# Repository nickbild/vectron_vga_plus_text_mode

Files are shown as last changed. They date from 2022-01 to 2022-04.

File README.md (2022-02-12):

# Vectron VGA Plus Text Mode

Vectron VGA Plus Text Mode simplifies displaying text with retro computers and microcontrollers by hiding the pixel-level details.  Supply only row and column positions, and an ASCII character code, to write text to a 40x30 character VGA display.

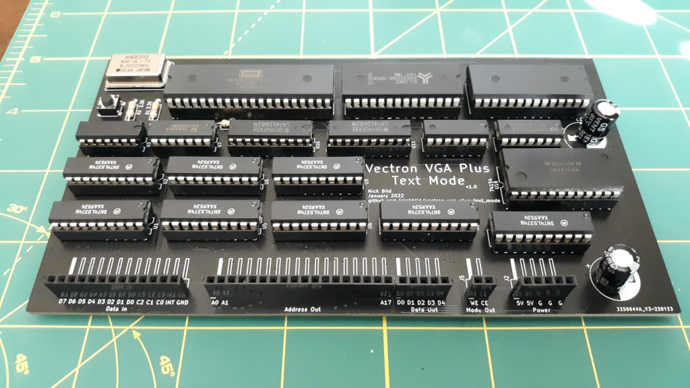
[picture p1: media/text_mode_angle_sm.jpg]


## How It Works

Vectron VGA Plus Text Mode accepts row, column, and character codes into 8-bit flip flop registers from external systems.  Using a 6502 processor and pre-programmed ROM chip ([code here](https://github.com/nickbild/vectron_vga_plus_text_mode/blob/main/os.asm)), these values are translated into a series of pixels to be drawn at x,y coordinates on the screen.  Both the program, and the library of available ASCII characters are stored in the ROM.  Instructions to draw each pixel are stored in 8-bit flip flop output registers where they can interface with and control a [Vectron VGA Plus](https://github.com/nickbild/vectron_vga_plus) VGA adapter.  Text Mode also handles initialization of a blank screen on the VGA adapter on startup.

To write a single 8x8 character to the screen without Text Mode would require writing 64 individual pixels, and performing all of the associated instructions and data transformations.  This would keep a typical 6502 computer pretty busy just writing to the screen, not to mention all of the other things the computer needs to do.  Text Mode allows for the same result with just a few instructions from the interfacing device.

At the heart of the design is a 65C02 processor to handle the somewhat complex calculations that would be difficult to perform with only logic chips, and would require a high part count.  I think using a microprocessor in this board is well within the bounds of being acceptable for a pure retro computing device, considering that the Commodore 1541 disk drive, for example, also had its own 6502 to handle processing.

An Arudino sketch that can be used to write characters using Text Mode [is here](https://github.com/nickbild/vectron_vga_plus_text_mode/tree/main/ardunio_tester).  KiCad design files are [available here](https://github.com/nickbild/vectron_vga_plus_text_mode/tree/main/kicad).  You will also need a [Vectron VGA Plus](https://github.com/nickbild/vectron_vga_plus) VGA adapter, which Text Mode was designed to work with.

## Media

Vectron VGA Plus Text Mode:

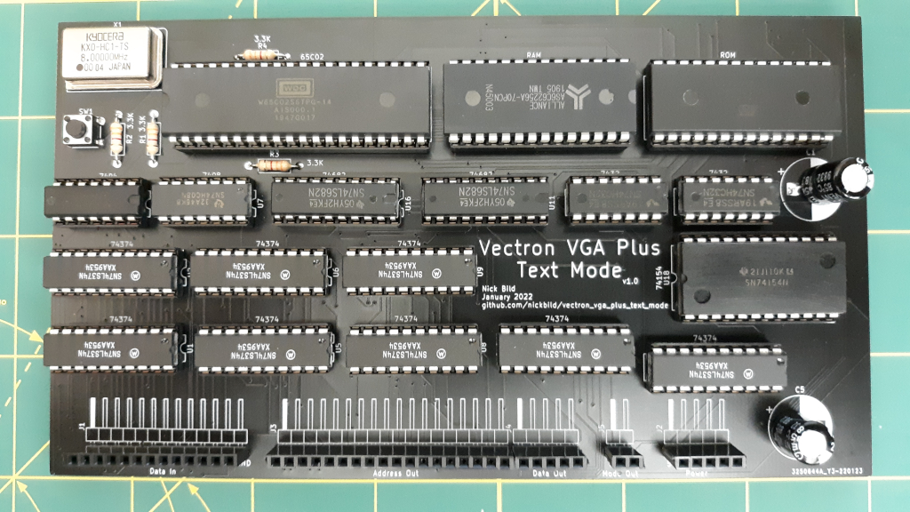
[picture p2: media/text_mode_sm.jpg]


Vectron VGA Plus Text Mode attached to Vectron VGA Plus, with an Arduino Mega 2560 requesting the characters to be written on screen:

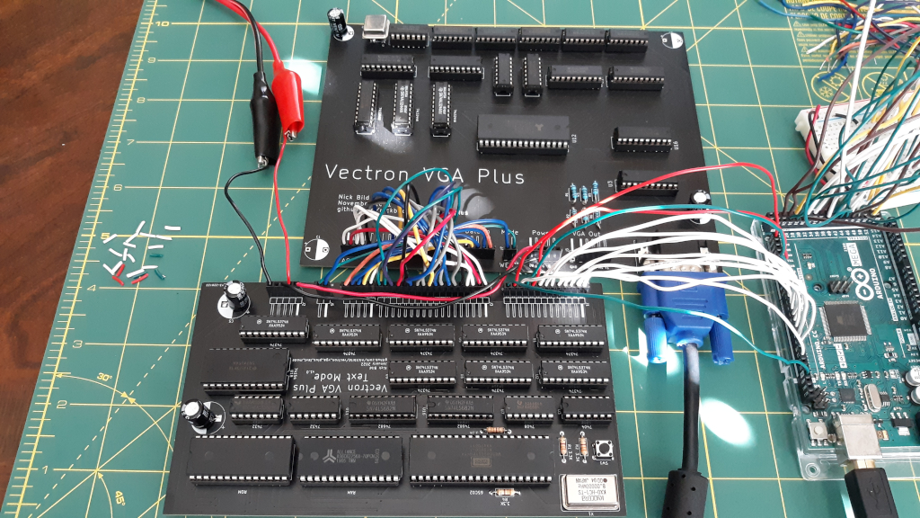
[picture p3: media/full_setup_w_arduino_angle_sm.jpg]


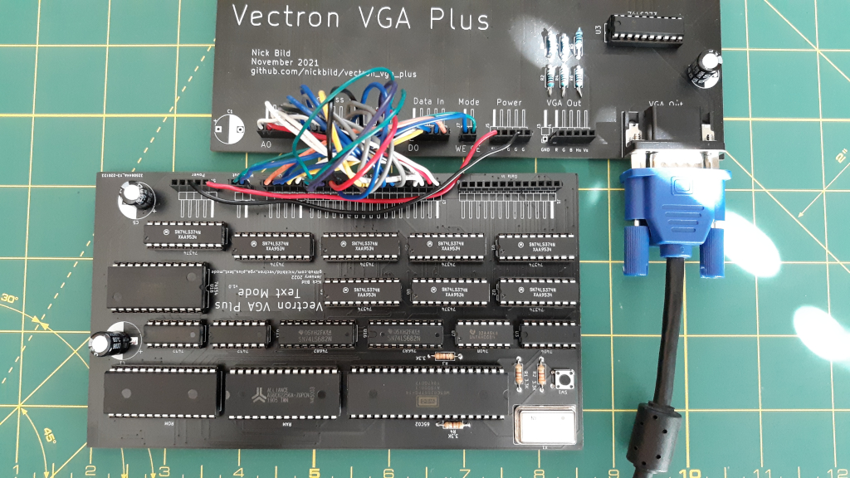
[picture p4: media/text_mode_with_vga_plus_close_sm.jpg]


All characters in a repeating pattern:

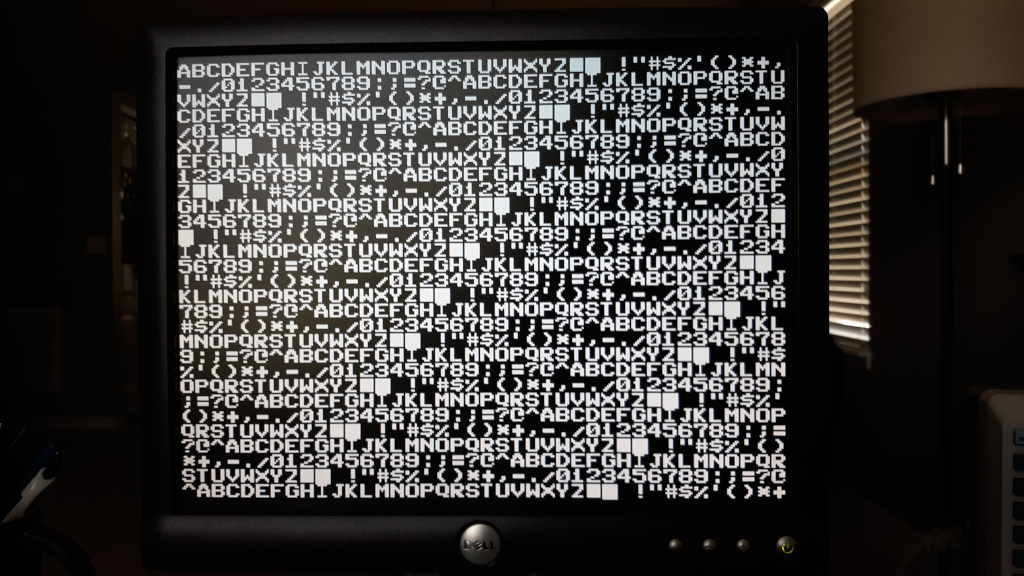
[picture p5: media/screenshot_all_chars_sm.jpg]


Text mode interface:

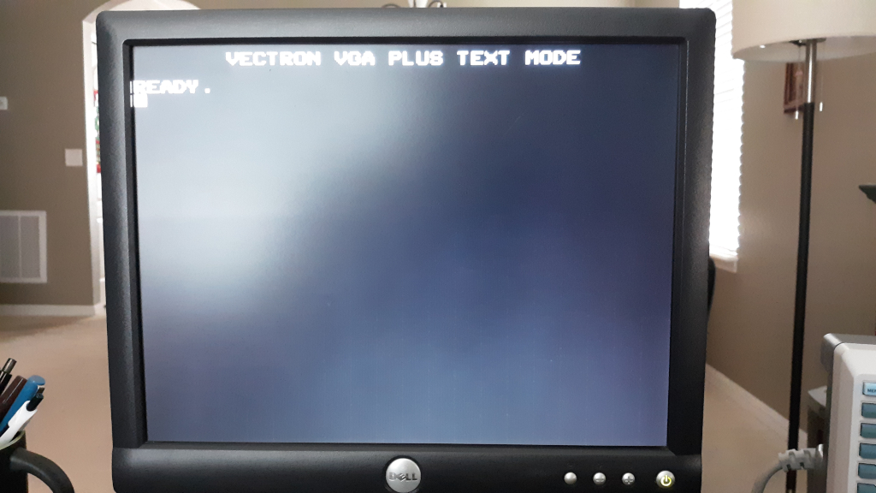
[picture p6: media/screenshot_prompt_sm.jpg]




Breadboard prototype (with a few components removed to place on the PCB):

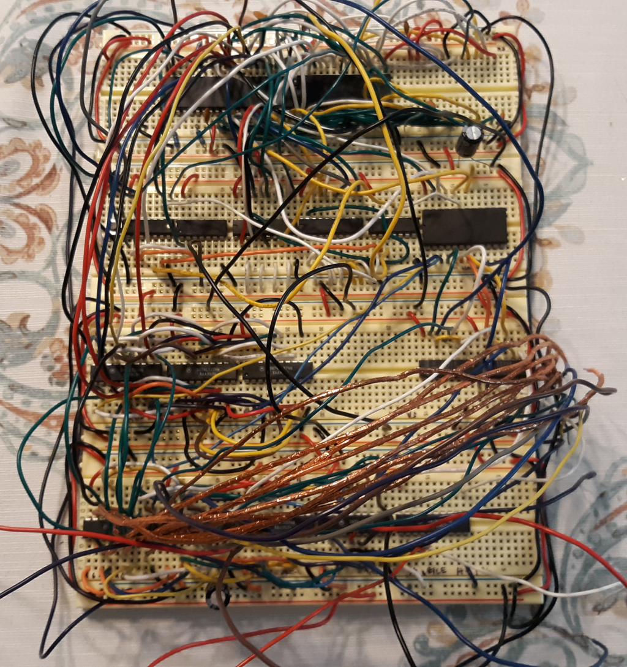
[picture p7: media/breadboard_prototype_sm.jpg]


## Bill of Materials

- 1 x WDC 65C02 processor
- 1 x AS6C62256A-70PCN 32KB RAM
- 1 x AT28C256-15PU 32KB ROM
- 1 x 8 MHz oscillator
- 4 x 3.3k ohm resistors
- 2 x 220 uF capacitors
- 1 x push button
- 2 x 7432
- 1 x 7408
- 1 x 7404
- 2 x 74682
- 1 x 74154
- 8 x 74374
- Female headers
- PCB ([KiCad design files](https://github.com/nickbild/vectron_vga_plus_text_mode/tree/main/kicad))

## About the Author

[Nick A. Bild, MS](https://nickbild79.firebaseapp.com/#!/)

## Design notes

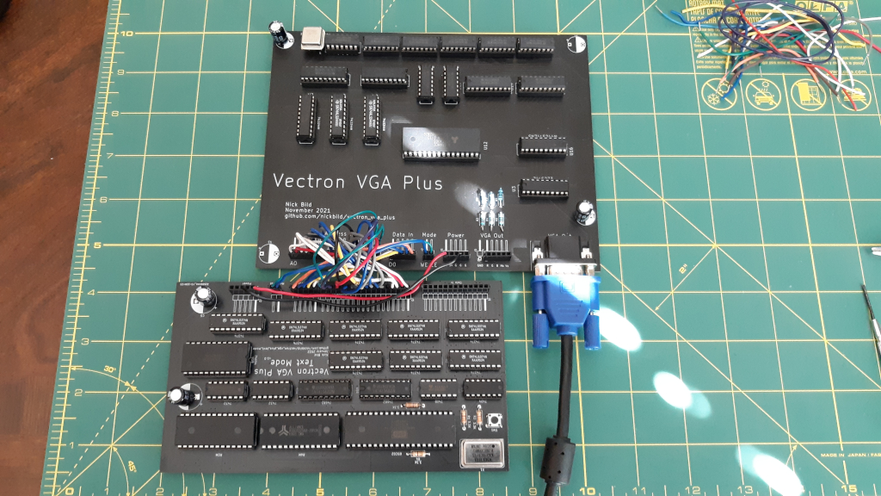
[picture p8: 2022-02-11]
media/text_mode_with_vga_plus_sm.jpg

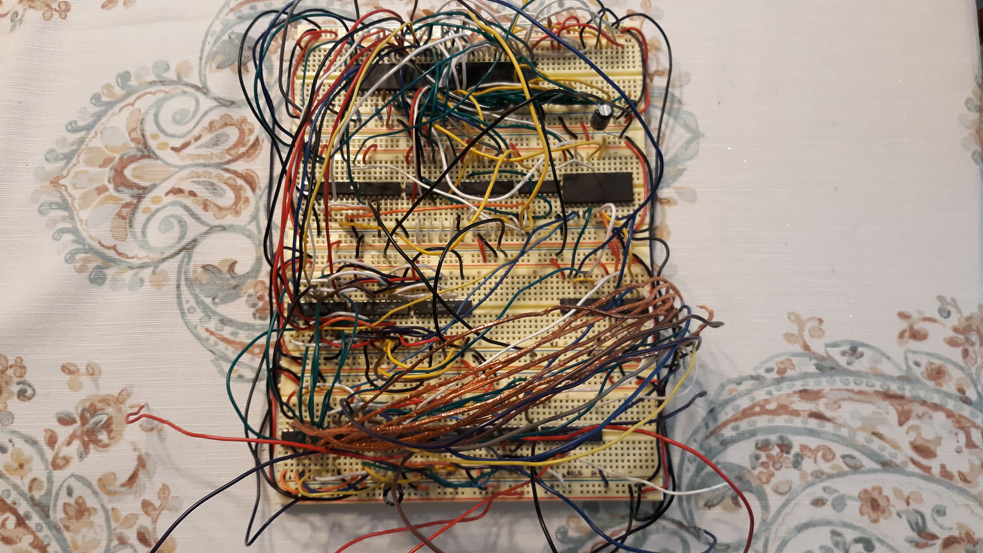
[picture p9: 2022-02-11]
media/breadboard_prototype.jpg

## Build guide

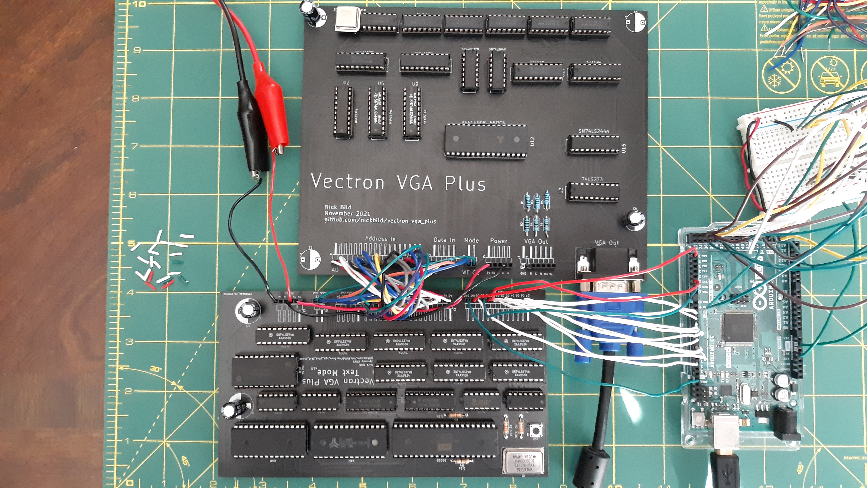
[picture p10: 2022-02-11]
media/full_setup_w_arduino.jpg

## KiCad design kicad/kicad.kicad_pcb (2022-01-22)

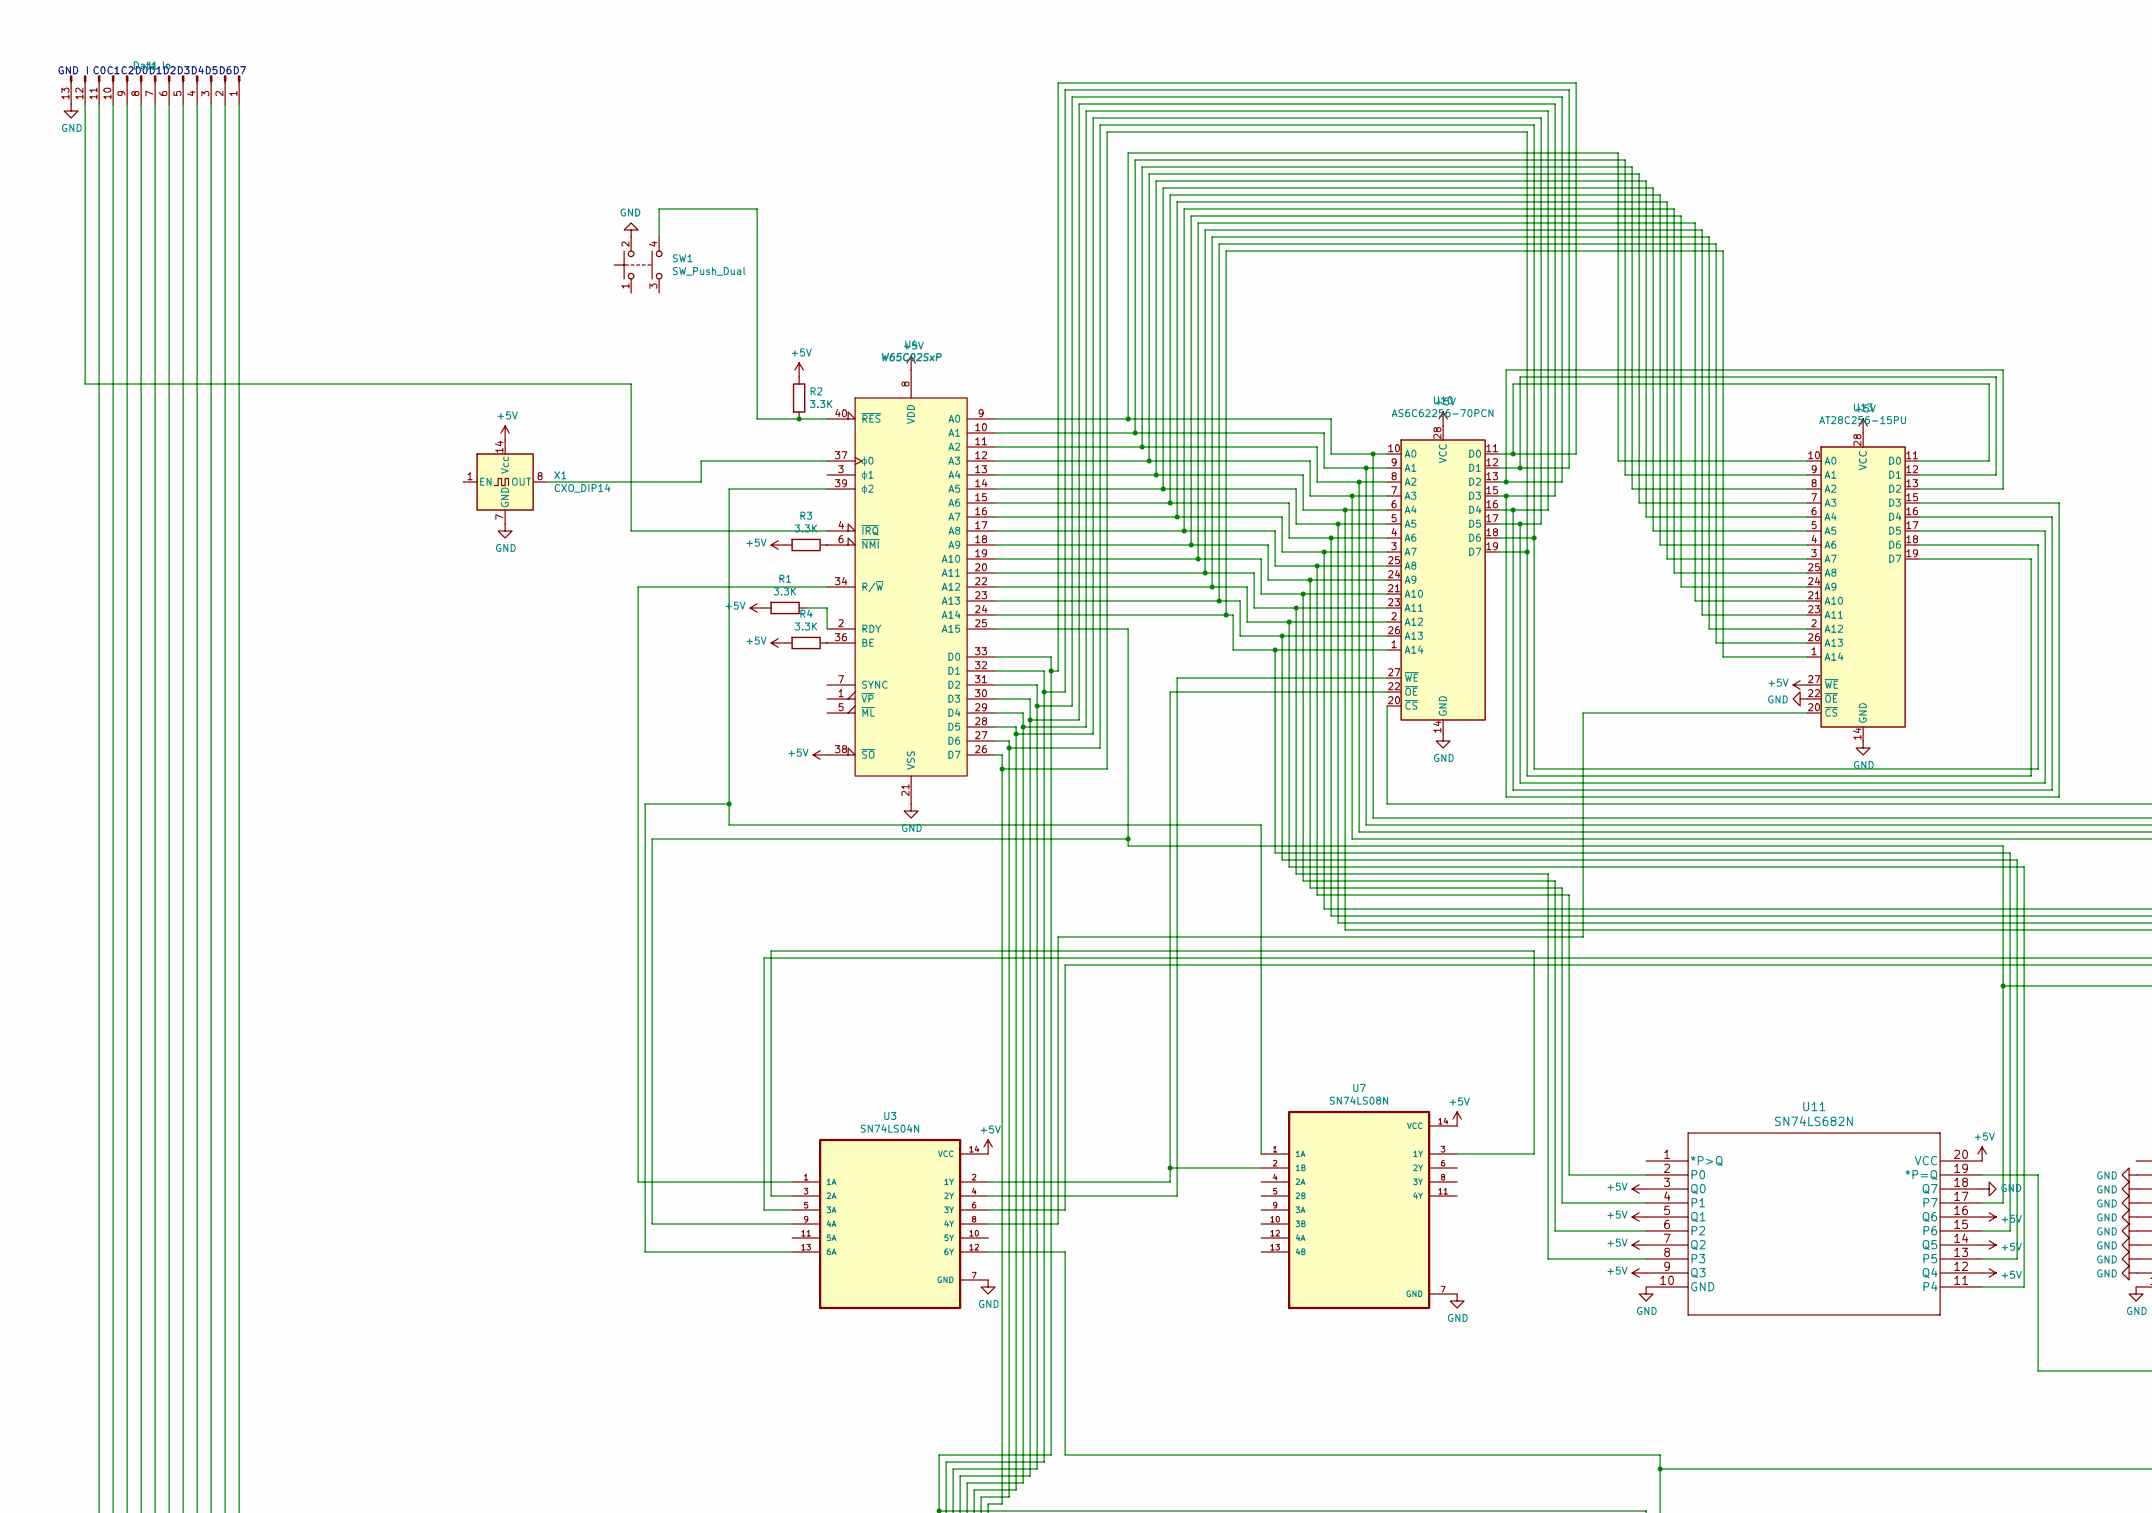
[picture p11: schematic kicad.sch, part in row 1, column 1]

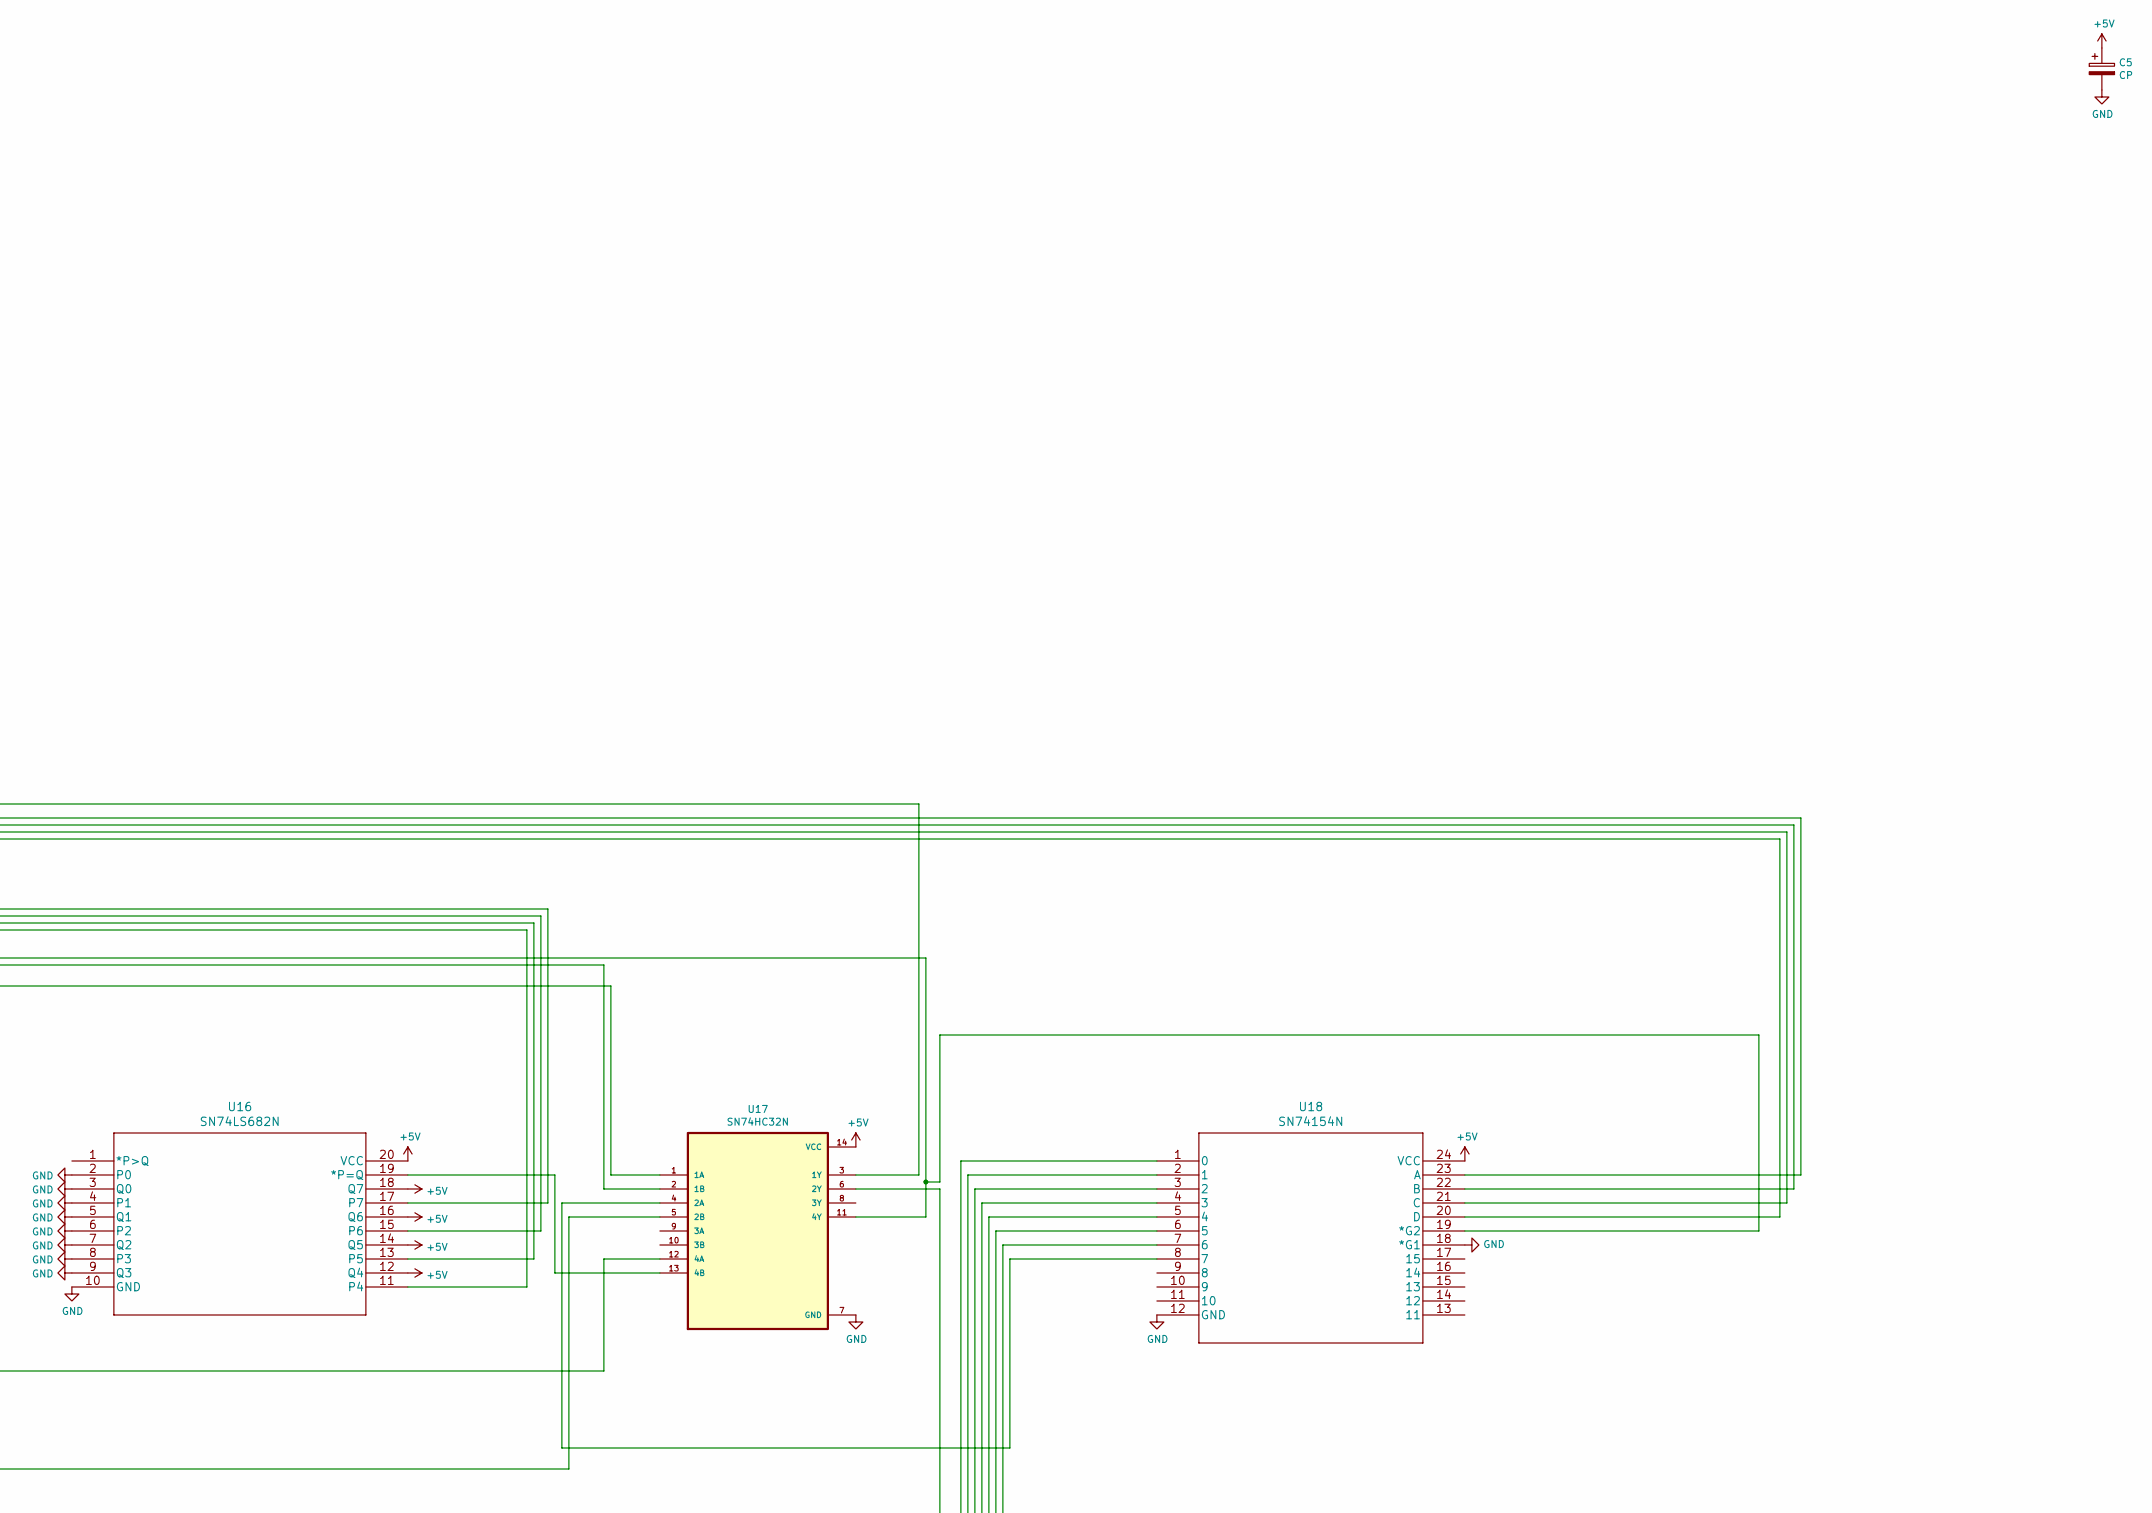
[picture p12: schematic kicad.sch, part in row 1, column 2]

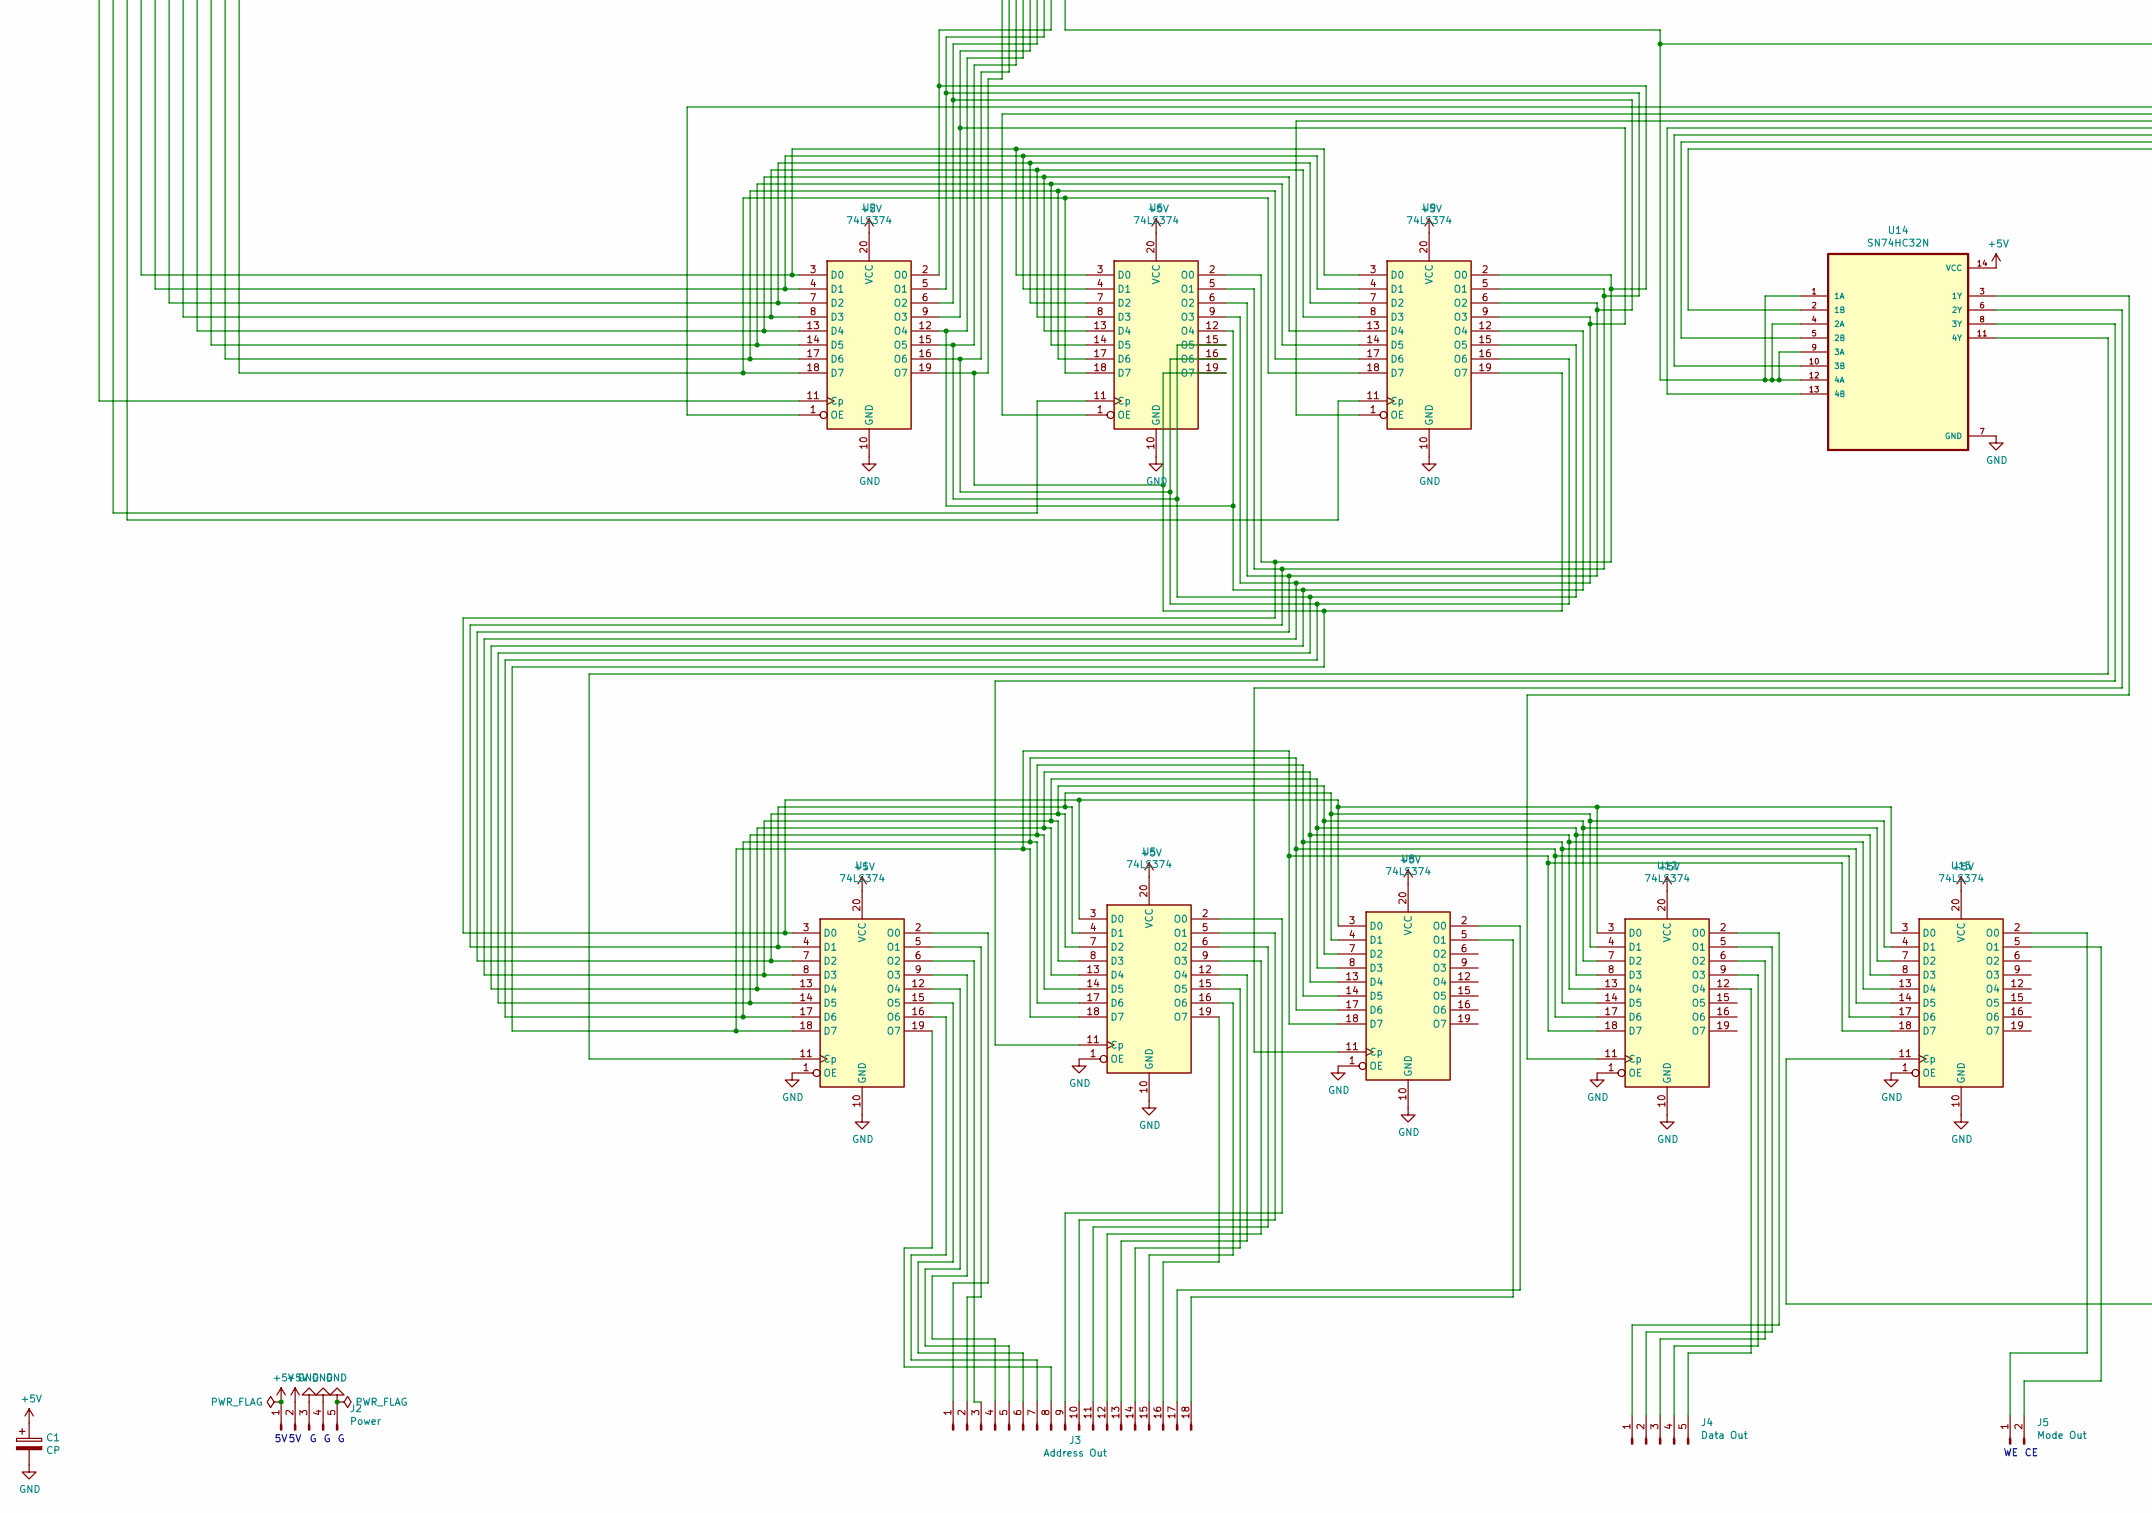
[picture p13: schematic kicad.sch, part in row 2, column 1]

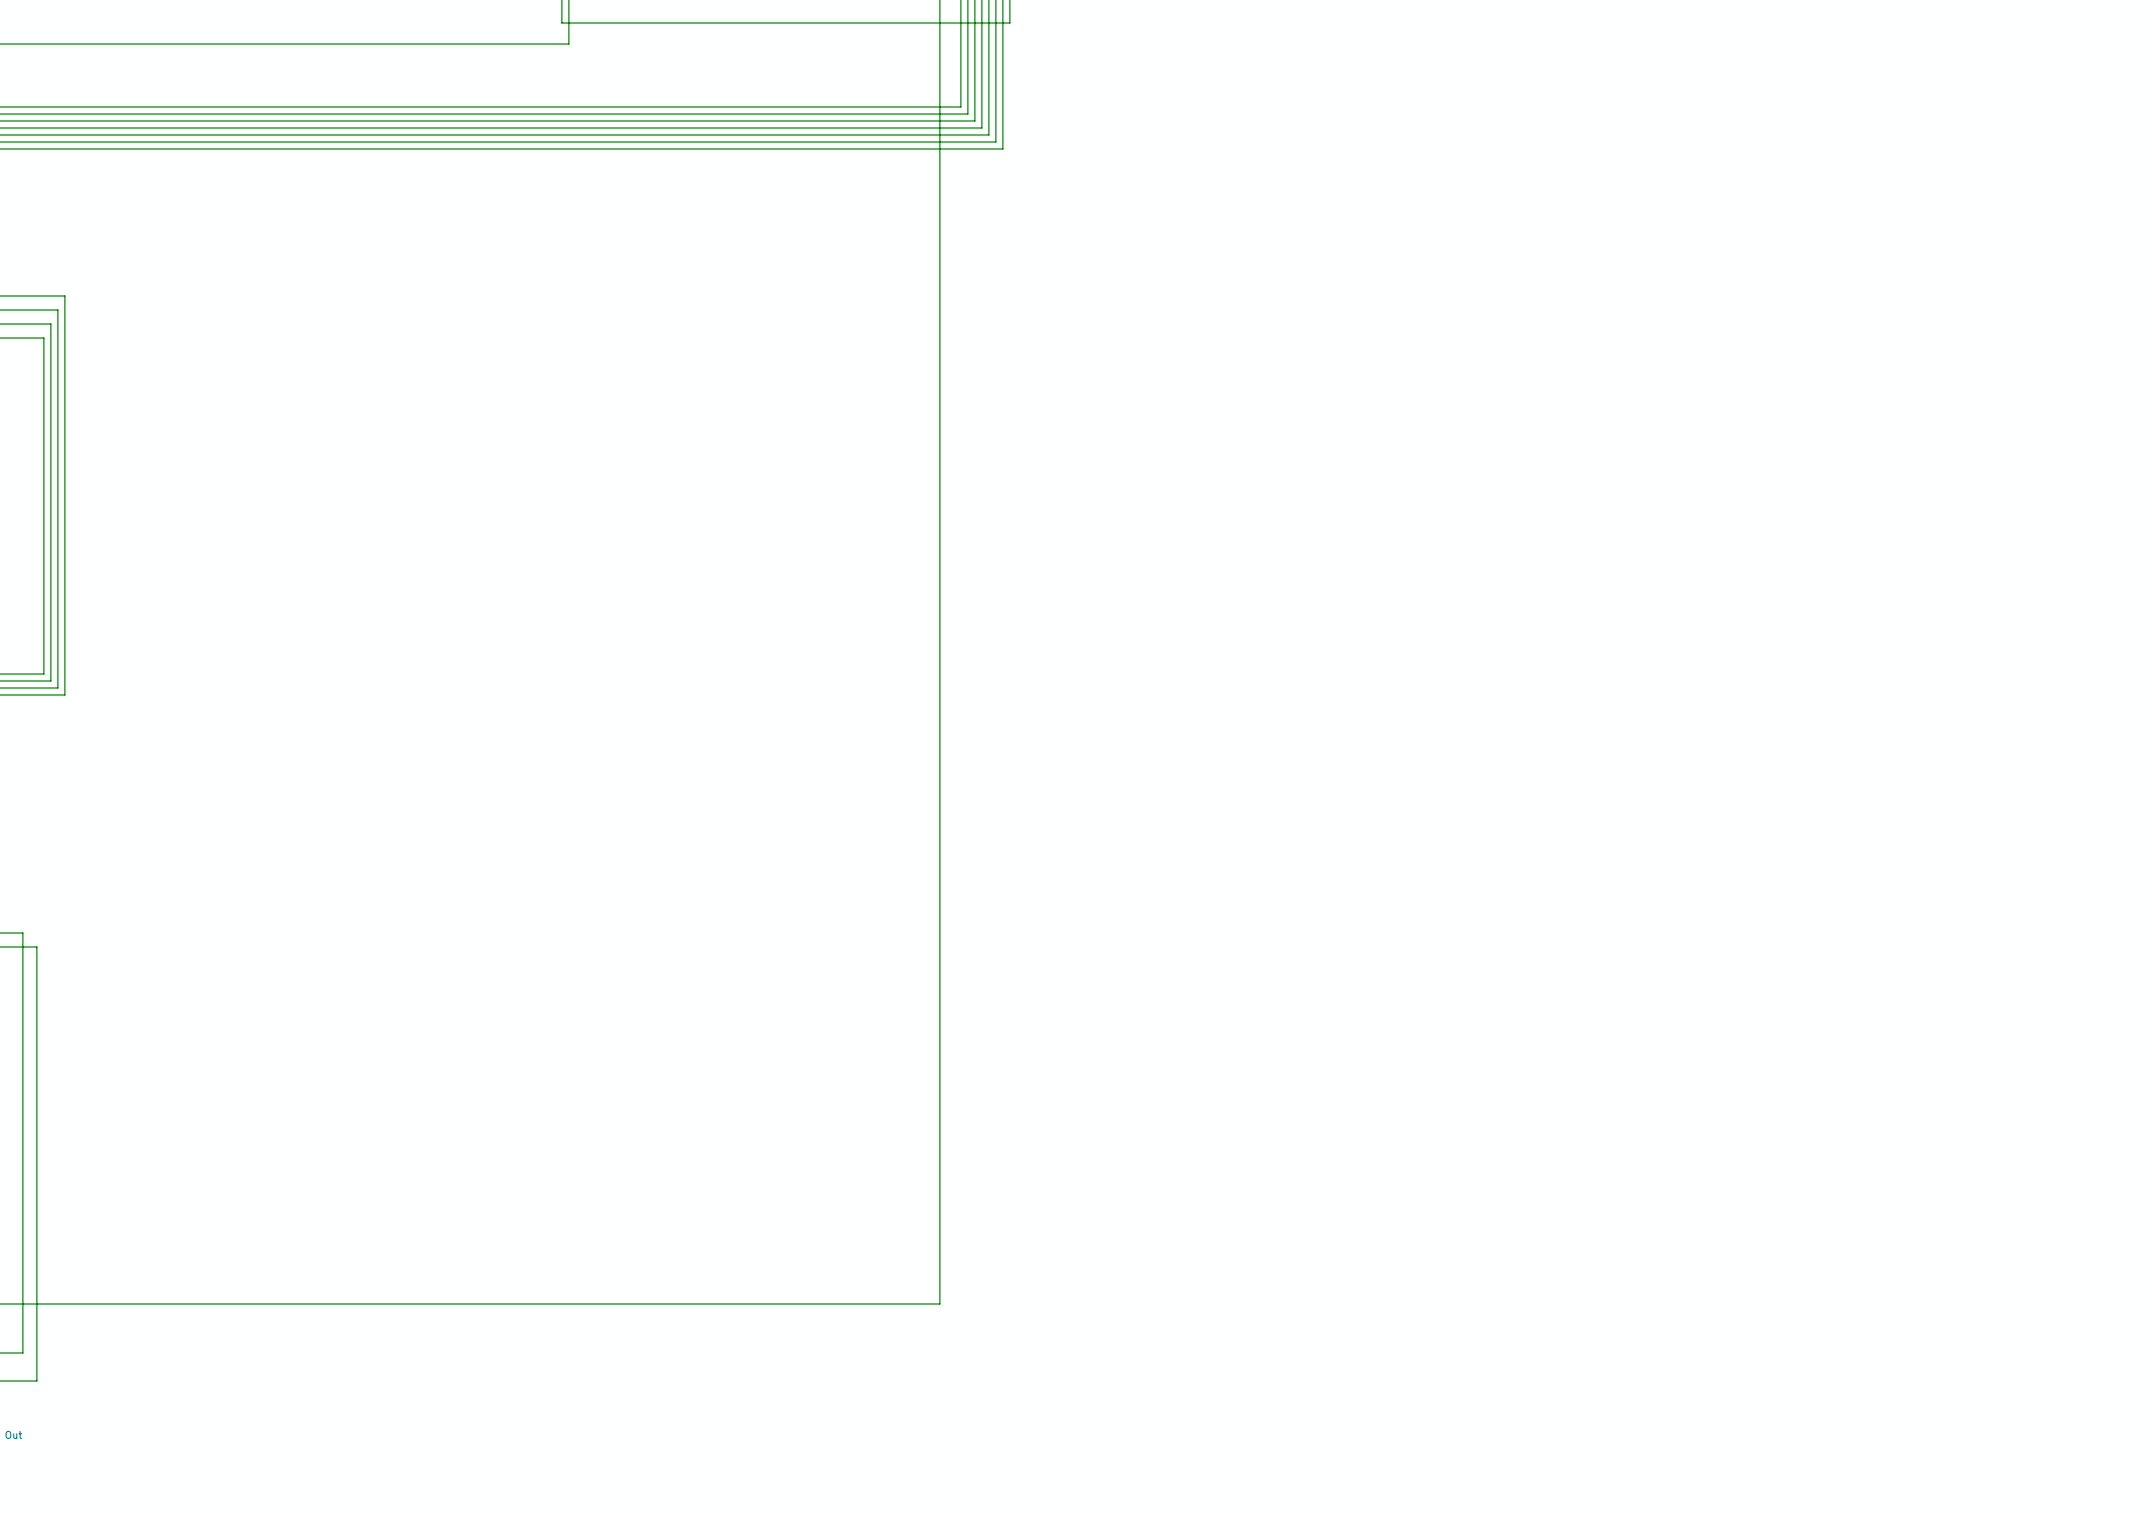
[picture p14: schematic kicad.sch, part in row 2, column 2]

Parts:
C1, C5: CP; CP_Radial_D12.5mm_P7.50mm
J1: Data In; PinHeader_1x13_P2.54mm_Horizontal
J2: Power; PinHeader_1x05_P2.54mm_Horizontal
J3: Address Out; PinHeader_1x18_P2.54mm_Horizontal
J4: Data Out; PinHeader_1x05_P2.54mm_Horizontal
J5: Mode Out; PinHeader_1x02_P2.54mm_Horizontal
R1, R2, R3, R4: 3.3K; R_Axial_DIN0207_L6.3mm_D2.5mm_P10.16mm_Horizontal
SW1: SW_Push_Dual; SW_TH_Tactile_Omron_B3F-10xx
U1, U2, U5, U6, U8, U9, U12, U15: 74LS374; DIP-20_W7.62mm
U3: SN74LS04N; DIP-14_W7.62mm
U4: W65C02SxP; DIP-40_W15.24mm
U7: SN74LS08N; DIP-14_W7.62mm
U10: AS6C62256-70PCN; DIP-28_W15.24mm
U11, U16: SN74LS682N; DIP-20_W7.62mm
U13: AT28C256-15PU; DIP-28_W15.24mm
U14, U17: SN74HC32N; DIP-14_W7.62mm
U18: SN74154N; DIP-24_W15.24mm
X1: CXO_DIP14; Oscillator_DIP-14

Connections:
+5V: C1.1, C5.1, J2.1, J2.2, R1.2, R2.1, R3.2, R4.2, U1.20 (VCC), U2.20 (VCC), U3.14 (VCC), U4.8 (VDD), U4.38 (~SO), U5.20 (VCC), U6.20 (VCC), U7.14 (VCC), U8.20 (VCC), U9.20 (VCC), U10.28 (VCC), U11.3 (Q0), U11.5 (Q1), U11.7 (Q2), U11.9 (Q3), U11.12 (Q4), U11.14 (Q5), U11.16 (Q6), U11.20 (VCC), U12.20 (VCC), U13.27 (~WE), U13.28 (VCC), U14.14 (VCC), U15.20 (VCC), U16.12 (Q4), U16.14 (Q5), U16.16 (Q6), U16.18 (Q7), U16.20 (VCC), U17.14 (VCC), U18.24 (VCC), X1.14 (Vcc)
GND: C1.2, C5.2, J1.13, J2.3, J2.4, J2.5, SW1.2, U1.1 (OE), U1.10 (GND), U2.10 (GND), U3.7 (GND), U4.21 (VSS), U5.1 (OE), U5.10 (GND), U6.10 (GND), U7.7 (GND), U8.1 (OE), U8.10 (GND), U9.10 (GND), U10.14 (GND), U11.10 (GND), U11.18 (Q7), U12.1 (OE), U12.10 (GND), U13.14 (GND), U13.22 (~OE), U14.7 (GND), U15.1 (OE), U15.10 (GND), U16.2 (P0), U16.3 (Q0), U16.4 (P1), U16.5 (Q1), U16.6 (P2), U16.7 (Q2), U16.8 (P3), U16.9 (Q3), U16.10 (GND), U17.7 (GND), U18.12 (GND), U18.18 (*G1), X1.7 (GND)
unnamed: J1.1, U2.18 (D7), U6.18 (D7), U9.18 (D7)
unnamed: J1.2, U2.17 (D6), U6.17 (D6), U9.17 (D6)
unnamed: J1.3, U2.14 (D5), U6.14 (D5), U9.14 (D5)
unnamed: J1.4, U2.13 (D4), U6.13 (D4), U9.13 (D4)
unnamed: J1.5, U2.8 (D3), U6.8 (D3), U9.8 (D3)
unnamed: J1.6, U2.7 (D2), U6.7 (D2), U9.7 (D2)
unnamed: J1.7, U2.4 (D1), U6.4 (D1), U9.4 (D1)
unnamed: J1.8, U2.3 (D0), U6.3 (D0), U9.3 (D0)
unnamed: J1.9, U9.11 (Cp)
unnamed: J1.10, U6.11 (Cp)
unnamed: J1.11, U2.11 (Cp)
unnamed: J1.12, U4.4 (~IRQ)
unnamed: J3.1, U1.2 (O0)
unnamed: J3.2, U1.5 (O1)
unnamed: J3.3, U1.6 (O2)
unnamed: J3.4, U1.9 (O3)
unnamed: J3.5, U1.12 (O4)
unnamed: J3.6, U1.15 (O5)
unnamed: J3.7, U1.16 (O6)
unnamed: J3.8, U1.19 (O7)
unnamed: J3.9, U5.2 (O0)
unnamed: J3.10, U5.5 (O1)
unnamed: J3.11, U5.6 (O2)
unnamed: J3.12, U5.9 (O3)
unnamed: J3.13, U5.12 (O4)
unnamed: J3.14, U5.15 (O5)
unnamed: J3.15, U5.16 (O6)
unnamed: J3.16, U5.19 (O7)
unnamed: J3.17, U8.2 (O0)
unnamed: J3.18, U8.5 (O1)
unnamed: J4.1, U12.2 (O0)
unnamed: J4.2, U12.5 (O1)
unnamed: J4.3, U12.6 (O2)
unnamed: J4.4, U12.9 (O3)
unnamed: J4.5, U12.12 (O4)
unnamed: J5.1, U15.2 (O0)
unnamed: J5.2, U15.5 (O1)
unnamed: R1.1, U4.2 (RDY)
unnamed: R2.2, SW1.4, U4.40 (~RES)
unnamed: R3.1, U4.6 (~NMI)
unnamed: R4.1, U4.36 (BE)
unnamed: U1.3 (D0), U2.2 (O0), U4.33 (D0), U5.3 (D0), U6.2 (O0), U8.3 (D0), U9.2 (O0), U10.11 (D0), U12.3 (D0), U13.11 (D0), U15.3 (D0)
unnamed: U1.4 (D1), U2.5 (O1), U4.32 (D1), U5.4 (D1), U6.5 (O1), U8.4 (D1), U9.5 (O1), U10.12 (D1), U12.4 (D1), U13.12 (D1), U15.4 (D1)
unnamed: U1.7 (D2), U2.6 (O2), U4.31 (D2), U5.7 (D2), U6.6 (O2), U8.7 (D2), U9.6 (O2), U10.13 (D2), U12.7 (D2), U13.13 (D2), U15.7 (D2)
unnamed: U1.8 (D3), U2.9 (O3), U4.30 (D3), U5.8 (D3), U6.9 (O3), U8.8 (D3), U9.9 (O3), U10.15 (D3), U12.8 (D3), U13.15 (D3), U15.8 (D3)
unnamed: U1.11 (Cp), U14.11 (4Y)
unnamed: U1.13 (D4), U2.12 (O4), U4.29 (D4), U5.13 (D4), U6.12 (O4), U8.13 (D4), U9.12 (O4), U10.16 (D4), U12.13 (D4), U13.16 (D4), U15.13 (D4)
unnamed: U1.14 (D5), U2.15 (O5), U4.28 (D5), U5.14 (D5), U6.15 (O5), U8.14 (D5), U9.15 (O5), U10.17 (D5), U12.14 (D5), U13.17 (D5), U15.14 (D5)
unnamed: U1.17 (D6), U2.16 (O6), U4.27 (D6), U5.17 (D6), U6.16 (O6), U8.17 (D6), U9.16 (O6), U10.18 (D6), U12.17 (D6), U13.18 (D6), U15.17 (D6)
unnamed: U1.18 (D7), U2.19 (O7), U4.26 (D7), U5.18 (D7), U6.19 (O7), U8.18 (D7), U9.19 (O7), U10.19 (D7), U12.18 (D7), U13.19 (D7), U15.18 (D7)
unnamed: U3.1 (1A), U4.34 (R/~W)
unnamed: U3.3 (2A), U7.3 (1Y)
unnamed: U3.13 (6A), U4.39 (ϕ2), U7.1 (1A)
unnamed: U4.37 (ϕ0), X1.8 (OUT)
unnamed: U4.24 (A14), U10.1 (A14), U11.15 (P6), U13.1 (A14)
unnamed: U4.22 (A12), U10.2 (A12), U11.11 (P4), U13.2 (A12)
unnamed: U4.16 (A7), U10.3 (A7), U13.3 (A7), U16.17 (P7)
unnamed: U4.15 (A6), U10.4 (A6), U13.4 (A6), U16.15 (P6)
unnamed: U4.14 (A5), U10.5 (A5), U13.5 (A5), U16.13 (P5)
unnamed: U4.13 (A4), U10.6 (A4), U13.6 (A4), U16.11 (P4)
unnamed: U4.12 (A3), U10.7 (A3), U13.7 (A3), U18.20 (D)
unnamed: U4.11 (A2), U10.8 (A2), U13.8 (A2), U18.21 (C)
unnamed: U4.10 (A1), U10.9 (A1), U13.9 (A1), U18.22 (B)
unnamed: U4.9 (A0), U10.10 (A0), U13.10 (A0), U18.23 (A)
unnamed: U10.20 (~CS), U17.3 (1Y)
unnamed: U4.19 (A10), U10.21 (A10), U11.6 (P2), U13.21 (A10)
unnamed: U3.2 (1Y), U7.2 (1B), U10.22 (~OE)
unnamed: U4.20 (A11), U10.23 (A11), U11.8 (P3), U13.23 (A11)
unnamed: U4.18 (A9), U10.24 (A9), U11.4 (P1), U13.24 (A9)
unnamed: U4.17 (A8), U10.25 (A8), U11.2 (P0), U13.25 (A8)
unnamed: U4.23 (A13), U10.26 (A13), U11.13 (P5), U13.26 (A13)
unnamed: U3.4 (2Y), U10.27 (~WE)
unnamed: U3.9 (4A), U4.25 (A15), U11.17 (P7), U17.1 (1A)
unnamed: U11.19 (*P=Q), U17.12 (4A)
unnamed: U12.11 (Cp), U14.3 (1Y)
unnamed: U3.8 (4Y), U13.20 (~CS)
unnamed: U3.12 (6Y), U14.1 (1A), U14.4 (2A), U14.9 (3A), U14.12 (4A), U17.5 (2B)
unnamed: U14.2 (1B), U18.7 (6)
unnamed: U14.5 (2B), U18.6 (5)
unnamed: U8.11 (Cp), U14.6 (2Y)
unnamed: U5.11 (Cp), U14.8 (3Y)
unnamed: U14.10 (3B), U18.5 (4)
unnamed: U14.13 (4B), U18.4 (3)
unnamed: U15.11 (Cp), U17.6 (2Y)
unnamed: U16.19 (*P=Q), U17.13 (4B)
unnamed: U3.6 (3Y), U17.2 (1B)
unnamed: U17.4 (2A), U18.8 (7)
unnamed: U3.5 (3A), U17.11 (4Y), U18.19 (*G2)
unnamed: U2.1 (OE), U18.1 (0)
unnamed: U6.1 (OE), U18.2 (1)
unnamed: U9.1 (OE), U18.3 (2)

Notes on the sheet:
GND

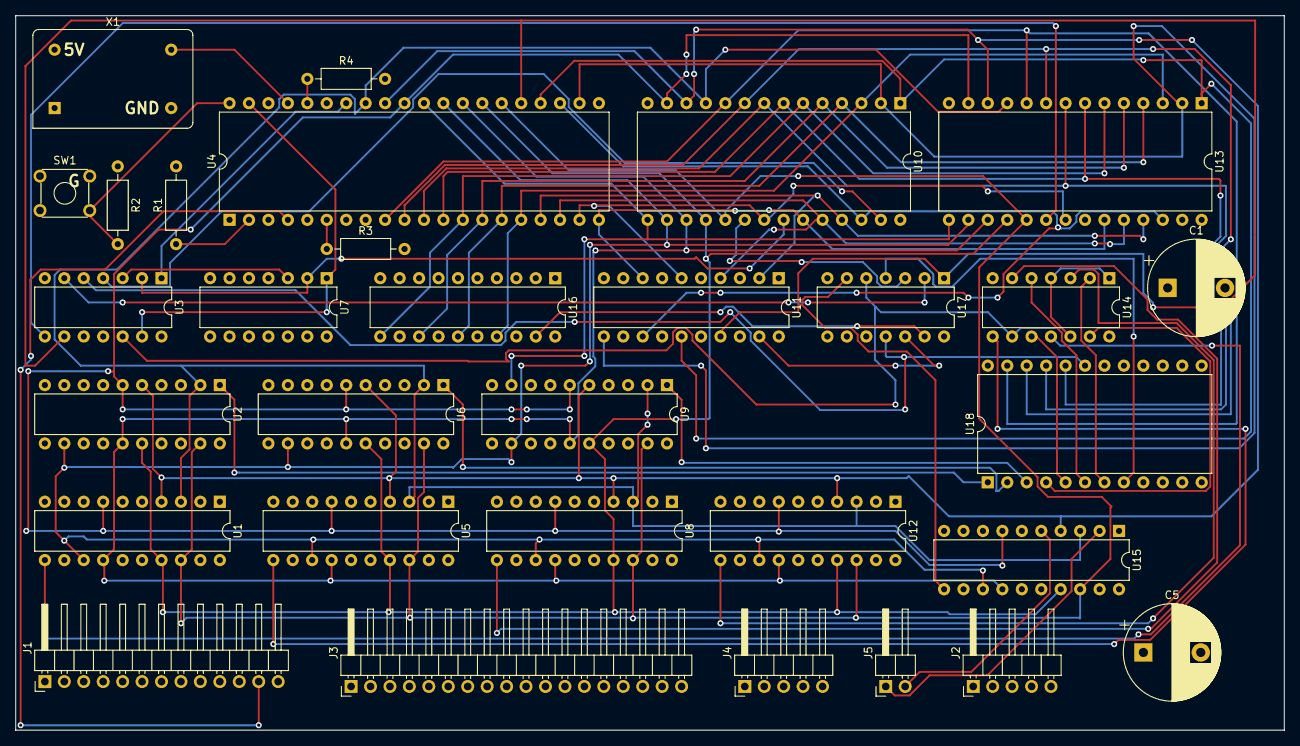
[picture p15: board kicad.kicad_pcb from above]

Board: 4 copper layers, 165.7 x 93.3 mm, 31 parts (0 on the bottom side), 93 nets.

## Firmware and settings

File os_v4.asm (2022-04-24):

;;;;
; Vectron VGA Plus Text Mode
;
; v2.0 - implement stack to minimize interrupt handling time.
;
; Nick Bild
; nick.bild@gmail.com
; February 2022
;
; Reserved memory:
;
; $0000-$7EFF - RAM
; 		$0000-$0017 - Named variables
;		$00C0-$00EF - Key press stack
; 		$0100-$01FF - 6502 stack
;		$7FF0-$7FFF - 16-bit Decoder
;			$7FF0 - Data input: Row
;			$7FF1 - Data input: Column
;			$7FF2 - Data input: RAM Value
;			$7FF3 - Data output: Address 0-7
;			$7FF4 - Data output: Address 8-15
;			$7FF5 - Data output: Address 16-17
;			$7FF6 - Data output: RAM Value
;			$7FF7 - Data output: WE/CE
; $8000-$FFFF - ROM
;		$8500		- IRQ Handler
;		$9500-$9CFF - Character Data
; 		$FFFA-$FFFB - NMI IRQ Vector
; 		$FFFC-$FFFD - Reset Vector - Stores start address of this ROM.
; 		$FFFE-$FFFF - IRQ Vector
;;;;

		processor 6502

		; Named variables in RAM.
		ORG $0000
addrLow
		.byte #$00
addrMid
		.byte #$00
addrHigh
		.byte #$00
data
		.byte #$00

num1Low
		.byte #$00
num1Mid
		.byte #$00
num1High
		.byte #$00
num2Low
		.byte #$00
num2Mid
		.byte #$00
num2High
		.byte #$00
resultLow
		.byte #$00
resultMid
		.byte #$00
resultHigh
		.byte #$00

charCode
		.byte #$00

bit0
		.byte #$00
bit1
		.byte #$00
bit2
		.byte #$00
bit3
		.byte #$00
bit4
		.byte #$00
bit5
		.byte #$00
bit6
		.byte #$00
bit7
		.byte #$00

SaveRow
		.byte #$00
SaveCol
		.byte #$00
SaveChar
		.byte #$00		

addrLowSave
		.byte #$00
addrMidSave
		.byte #$00
addrHighSave
		.byte #$00

StartExe	ORG $8000

	sei						; Disable interrupts.

	; Write blank VGA signal to both RAM chips.

	; Set Vectron VGA Plus memory counter to 0.
	lda #$00
	sta addrLow
	sta addrMid
	sta addrHigh

	; Set inital state of WE/CE on Vectron VGA Plus.
	lda #$03
	sta $7FF7				; WE/CE high
	
	; Write VGA signal timings for a blank screen to memory.
	jsr SetupVGA

	lda #$01
	sta $7FF7				; CE low (read mode)

	; Set Vectron VGA Plus memory counter to 0.
	lda #$00
	sta addrLow
	sta addrMid
	sta addrHigh

	; Set inital state of WE/CE on Vectron VGA Plus.
	lda #$03
	sta $7FF7				; WE/CE high
	
	; Write VGA signal timings for a blank screen to memory.
	jsr SetupVGA

	lda #$01
	sta $7FF7				; CE low (read mode)

	cli						; Enable interrupts.


; Do nothing - wait for an interrupt.
MainLoop:
    jmp MainLoop


SetupVGA
	; Visible lines and vertical front porch.

	; 489 * visible line.
	ldy #$FF
SetupVGA1
	jsr DrawVisibleLine
	dey
	bne SetupVGA1

	ldy #$EA
SetupVGA2
	jsr DrawVisibleLine
	dey
	bne SetupVGA2

	; Vertical sync.
	jsr VSync

	; vertical back porch
	ldy #$21
SetupVGA3
	jsr DrawVisibleLine
	dey
	bne SetupVGA3

	; Finish last row.
	lda #$18		; 24
	sta data

	ldy #$10
SetupVGA4
	jsr WriteDataInit
	dey
	bne SetupVGA4
	
	rts


DrawVisibleLine
	.byte #$DA ; phx - mnemonic unknown to DASM.
	.byte #$5A ; phy

	; 328 * 24;  48 * 16;  24 * 24
	
	lda #$18		; 24
	sta data

	ldx #$FF
Visible1
	jsr WriteDataInit
	dex
	bne Visible1

	ldx #$49
Visible2
	jsr WriteDataInit
	dex
	bne Visible2

	lda #$10		; 16
	sta data

	ldx #$30
Visible3
	jsr WriteDataInit
	dex
	bne Visible3

	lda #$18		; 24
	sta data

	ldx #$18
Visible4
	jsr WriteDataInit
	dex
	bne Visible4
 
	.byte #$7A ; ply
	.byte #$FA ; plx

	rts


VSync
	.byte #$DA ; phx - mnemonic unknown to DASM.
	.byte #$5A ; phy

	; 320 * 24;  8 * 8;  48 * 0;  24 * 8
	
	lda #$18		; 24
	sta data

	ldx #$FF
VSync1
	jsr WriteDataInit
	dex
	bne VSync1

	ldx #$41
VSync2
	jsr WriteDataInit
	dex
	bne VSync2

	lda #$08		; 8
	sta data

	ldx #$08
VSync3
	jsr WriteDataInit
	dex
	bne VSync3

	lda #$00		; 0
	sta data

	ldx #$30
VSync4
	jsr WriteDataInit
	dex
	bne VSync4

	lda #$08		; 8
	sta data

	ldx #$18
VSync5
	jsr WriteDataInit
	dex
	bne VSync5


	; 320 * 8;  8 * 8;  48 * 0;  24 * 8
	
	lda #$08		; 8
	sta data

	ldx #$FF
VSync6
	jsr WriteDataInit
	dex
	bne VSync6

	ldx #$41
VSync7
	jsr WriteDataInit
	dex
	bne VSync7

	lda #$08		; 8
	sta data

	ldx #$08
VSync8
	jsr WriteDataInit
	dex
	bne VSync8

	lda #$00		; 0
	sta data

	ldx #$30
VSync9
	jsr WriteDataInit
	dex
	bne VSync9

	lda #$08		; 8
	sta data

	ldx #$18
VSync10
	jsr WriteDataInit
	dex
	bne VSync10


	; 320 * 8;  8 * 24;  48 * 16;  24 * 24
	
	lda #$08		; 8
	sta data

	ldx #$FF
VSync11
	jsr WriteDataInit
	dex
	bne VSync11

	ldx #$41
VSync12
	jsr WriteDataInit
	dex
	bne VSync12

	lda #$18		; 24
	sta data

	ldx #$08
VSync13
	jsr WriteDataInit
	dex
	bne VSync13

	lda #$10		; 16
	sta data

	ldx #$30
VSync14
	jsr WriteDataInit
	dex
	bne VSync14

	lda #$18		; 24
	sta data

	ldx #$18
VSync15
	jsr WriteDataInit
	dex
	bne VSync15

	.byte #$7A ; ply
	.byte #$FA ; plx

	rts


; This version requires the data value to be stored at 'data'.
WriteDataInit
	; Set up the address and data output flip flops.
	lda addrLow
	sta $7FF3

	lda addrMid
	sta $7FF4

	lda addrHigh
	sta $7FF5

	lda data
	sta $7FF6

	; Latch data into Vectron VGA Plus memory.
	lda #$02
	sta $7FF7				; WE low

	lda #$00
	sta $7FF7				; WE/CE low
	
	lda #$02
	sta $7FF7				; WE low

	lda #$03
	sta $7FF7				; WE/CE high

	; Increment address counter.
	inc addrLow
	bne IncAddress1Init
	inc addrMid
	bne IncAddress1Init
	inc addrHigh
IncAddress1Init

	rts


; This version requires the data value to be in the accumulator.
WriteData
	; Set up the address and data output flip flops.

	; Accumulator has data value when this sub is called.
	sta $7FF6

	lda addrLow
	sta $7FF3

	lda addrMid
	sta $7FF4

	lda addrHigh
	sta $7FF5

	; Latch data into Vectron VGA Plus memory.
	lda #$02
	sta $7FF7				; WE low

	lda #$00
	sta $7FF7				; WE/CE low
	
	lda #$02
	sta $7FF7				; WE low

	lda #$03
	sta $7FF7				; WE/CE high

	; Increment address counter.
	inc addrLow
	bne IncAddress1
	inc addrMid
	bne IncAddress1
	inc addrHigh
IncAddress1

	rts


Add24BitNumbers
	clc
	lda num1Low
	adc num2Low
	sta num1Low
	
	lda num1Mid
	adc num2Mid
	sta num1Mid

	lda num1High
	adc num2High
	sta num1High

	rts


NextAddressRow
	; Add 392 to address.
	clc
	lda addrLow
	adc #$88
	sta addrLow
	
	lda addrMid
	adc #$01
	sta addrMid

	lda addrHigh
	adc #$00
	sta addrHigh

	rts
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

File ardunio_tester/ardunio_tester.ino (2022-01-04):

// Data bus.
#define DATA0 2
#define DATA1 3
#define DATA2 4
#define DATA3 5
#define DATA4 6
#define DATA5 7
#define DATA6 8
#define DATA7 9

// Flip flop clocks.
#define C0 11
#define C1 15
#define C2 16

// 6502 interrupt.
#define INT 21

void setup() {
  Serial.begin(9600);

  pinMode(DATA0, OUTPUT);
  pinMode(DATA1, OUTPUT);
  pinMode(DATA2, OUTPUT);
  pinMode(DATA3, OUTPUT);
  pinMode(DATA4, OUTPUT);
  pinMode(DATA5, OUTPUT);
  pinMode(DATA6, OUTPUT);
  pinMode(DATA7, OUTPUT);

  pinMode(C0, OUTPUT);
  pinMode(C1, OUTPUT);
  pinMode(C2, OUTPUT);

  pinMode(INT, OUTPUT);


  digitalWrite(C0, LOW);
  digitalWrite(C1, LOW);
  digitalWrite(C2, LOW);

  digitalWrite(INT, HIGH);
}

uint8_t code = 97;

void loop() {
  Serial.println("Reset video now...");
  delay(8000);
  Serial.println("Go!");

  // VECTRON VGA PLUS TEXT MODE
  writeCharacter(7, 1, 118);
  writeCharacter(8, 1, 101);
  writeCharacter(9, 1, 99);
  writeCharacter(10, 1, 116);
  writeCharacter(11, 1, 114);
  writeCharacter(12, 1, 111);
  writeCharacter(13, 1, 110);

  writeCharacter(15, 1, 118);
  writeCharacter(16, 1, 103);
  writeCharacter(17, 1, 97);

  writeCharacter(19, 1, 112);
  writeCharacter(20, 1, 108);
  writeCharacter(21, 1, 117);
  writeCharacter(22, 1, 115);

  writeCharacter(24, 1, 116);
  writeCharacter(25, 1, 101);
  writeCharacter(26, 1, 120);
  writeCharacter(27, 1, 116);

  writeCharacter(29, 1, 109);
  writeCharacter(30, 1, 111);
  writeCharacter(31, 1, 100);
  writeCharacter(32, 1, 101);

  // READY.
  writeCharacter(0, 3, 114);
  writeCharacter(1, 3, 101);
  writeCharacter(2, 3, 97);
  writeCharacter(3, 3, 100);
  writeCharacter(4, 3, 121);
  writeCharacter(5, 3, 46);

  writeCharacter(0, 4, 127);

  // 
  for (int j=6; j<30; j++) {
    for (int i=0; i<40; i++) {
    
      writeCharacter(i, j, code);

      code += 1;
      if (code == 123) {
        code = 127;
      } else if (code == 128) {
        code = 1;
      } else if (code == 2) {
        code = 32;
      } else if (code == 38) {
        code = 39;
      } else if (code == 60) {
        code = 61;
      } else if (code == 62) {
        code = 63;
      } else if (code == 65) {
        code = 94;
      } else if (code == 95) {
        goto Done;
      }
      
    }
  }

Done:

// Fill screen with all characters:
//  for (int j=1; j<30; j++) {
//    for (int i=0; i<40; i++) {
//    
//      writeCharacter(i, j, code);
//
//      code += 1;
//      if (code == 123) {
//        code = 127;
//      } else if (code == 128) {
//        code = 1;
//      } else if (code == 2) {
//        code = 32;
//      } else if (code == 38) {
//        code = 39;
//      } else if (code == 60) {
//        code = 61;
//      } else if (code == 62) {
//        code = 63;
//      } else if (code == 65) {
//        code = 94;
//      } else if (code == 95) {
//        code = 97;
//      }
//      
//    }
//  }

  while (true) {}
}

void writeCharacter(uint8_t col, uint8_t row, uint8_t charCode) {
  // Row (0-29)
  digitalWrite(DATA0, bitRead(row, 0));
  digitalWrite(DATA1, bitRead(row, 1));
  digitalWrite(DATA2, bitRead(row, 2));
  digitalWrite(DATA3, bitRead(row, 3));
  digitalWrite(DATA4, bitRead(row, 4));
  digitalWrite(DATA5, bitRead(row, 5));
  digitalWrite(DATA6, bitRead(row, 6));
  digitalWrite(DATA7, bitRead(row, 7));

  digitalWrite(C0, HIGH);
  digitalWrite(C0, LOW);

  // Column (0-39)
  digitalWrite(DATA0, bitRead(col, 0));
  digitalWrite(DATA1, bitRead(col, 1));
  digitalWrite(DATA2, bitRead(col, 2));
  digitalWrite(DATA3, bitRead(col, 3));
  digitalWrite(DATA4, bitRead(col, 4));
  digitalWrite(DATA5, bitRead(col, 5));
  digitalWrite(DATA6, bitRead(col, 6));
  digitalWrite(DATA7, bitRead(col, 7));

  digitalWrite(C1, HIGH);
  digitalWrite(C1, LOW);

  // Character
  digitalWrite(DATA0, bitRead(charCode, 0));
  digitalWrite(DATA1, bitRead(charCode, 1));
  digitalWrite(DATA2, bitRead(charCode, 2));
  digitalWrite(DATA3, bitRead(charCode, 3));
  digitalWrite(DATA4, bitRead(charCode, 4));
  digitalWrite(DATA5, bitRead(charCode, 5));
  digitalWrite(DATA6, bitRead(charCode, 6));
  digitalWrite(DATA7, bitRead(charCode, 7));

  digitalWrite(C2, HIGH);
  digitalWrite(C2, LOW);

  digitalWrite(INT, LOW);
  digitalWrite(INT, HIGH);
  delay(5); // Give interrupt time to be serviced.
}

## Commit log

2022-01-02 Fix a few character codes.
    [os.asm]
2022-01-04 Arduino sketch to test text mode.
2022-01-08 Save progress on schematics.
    [kicad.kicad_pcb, kicad.sch]
2022-01-17 Finished schematics.
    [kicad.sch]
2022-01-18 Save progress on PCB.
    [kicad.sch]
2022-01-22 Add gerbers.
    [kicad-B_Cu.gbl, kicad-B_Mask.gbs, kicad-B_Paste.gbp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]
2022-02-17 Add upper case character codes.
